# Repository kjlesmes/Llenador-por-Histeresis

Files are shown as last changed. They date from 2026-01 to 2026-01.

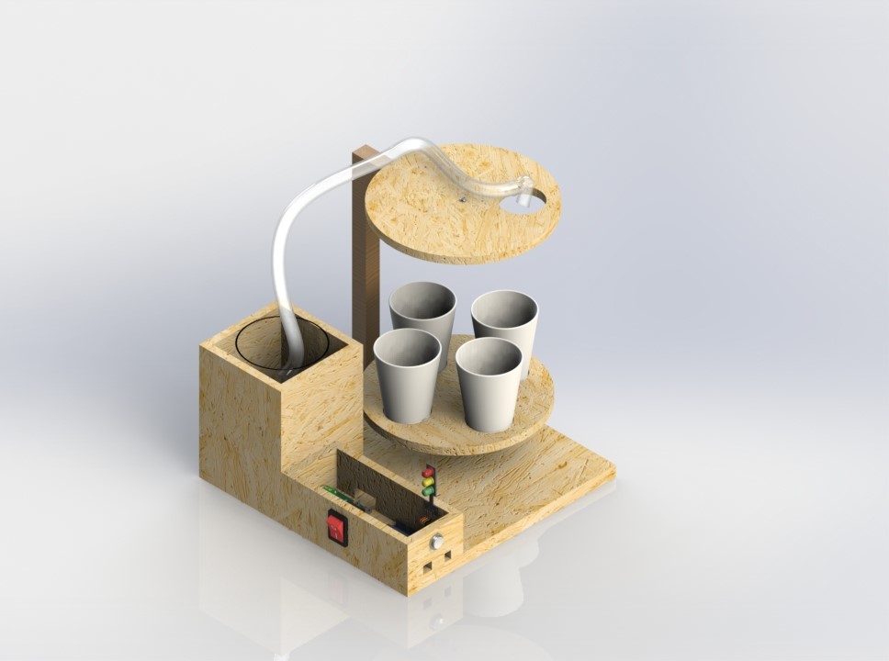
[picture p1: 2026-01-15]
Ensamble.JPG

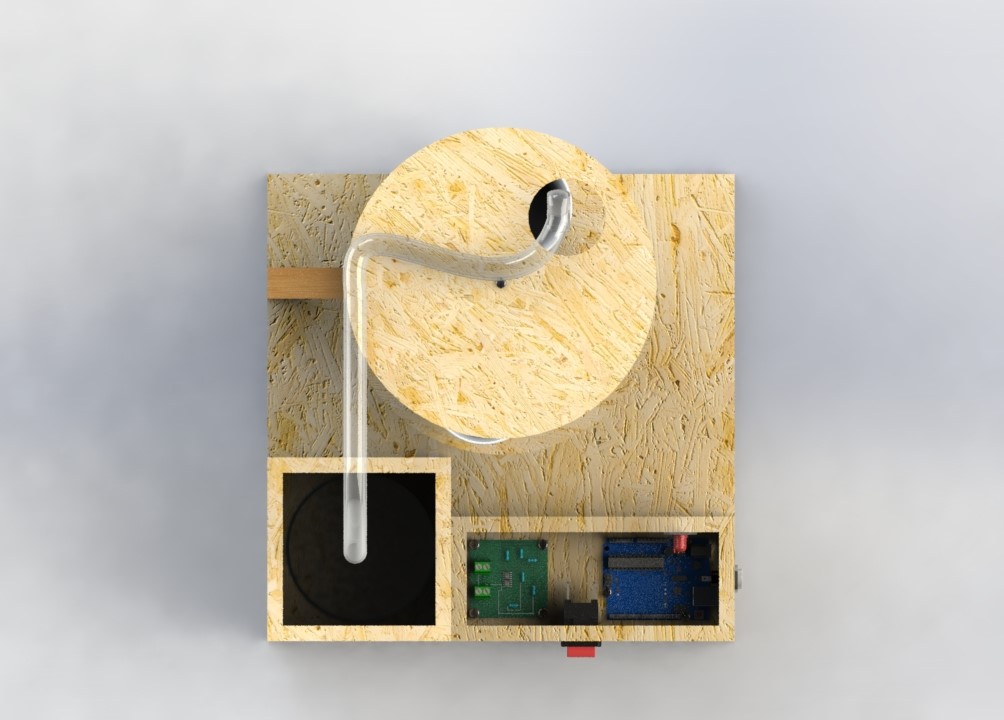
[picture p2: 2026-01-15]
Vista_5.JPG

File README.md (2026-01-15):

# Llenador por Histéresis

## Descripción

Sistema de llenado de líquidos basado en control por histéresis. Este proyecto incluye el diseño mecánico completo de un dispositivo automatizado para el llenado preciso de envases mediante un mecanismo de plato giratorio.

## Estructura del Proyecto

El proyecto está compuesto por los siguientes archivos CAD desarrollados en SolidWorks:

| Archivo | Tipo | Descripción |
|---|---|---|
| `PCB.SLDASM` | Ensamblaje | Ensamblaje principal de la placa de circuito impreso |
| `Base PCB.SLDPRT` | Pieza | Base de soporte para la PCB |
| `Base_Estructura.SLDPRT` | Pieza | Base estructural del sistema |
| `Envase_Agua.SLDPRT` | Pieza | Contenedor de agua/líquido |
| `Plato Giratorio.SLDPRT` | Pieza | Plato rotativo para posicionamiento de envases |
| `Plato_Superior.SLDPRT` | Pieza | Plato superior del mecanismo |
| `Vaso.SLDPRT` | Pieza | Recipiente para llenado |

## Componentes del Sistema

### Mecánicos
- Base estructural principal
- Sistema de plato giratorio para indexación de envases
- Soporte para PCB de control

### Electrónicos
- Placa de circuito impreso (PCB) para control por histéresis
- Sensores de nivel
- Actuadores de llenado

## Principio de Funcionamiento

El sistema utiliza control por histéresis para regular el proceso de llenado:

1. El plato giratorio posiciona el envase en la estación de llenado
2. El sensor de nivel detecta el estado del recipiente
3. El controlador activa/desactiva el flujo según los umbrales de histéresis definidos
4. Una vez alcanzado el nivel objetivo, el plato rota para posicionar el siguiente envase

## Requisitos de Software

- SolidWorks 2020 o superior (para visualización y edición de archivos CAD)
- el acceso a este proyecto completo esta optimizado en mi Drive personal debido a la limitacion de subida de archivos de >25MB de Github. no todos los archivos estan en este repo. https://drive.google.com/drive/folders/1w_ededs4AJgMJ44YJDUHpp9wmpBniWWi

## Licencia

Proyecto de portafolio personal.

## Autor

Ing. Karen lesmes

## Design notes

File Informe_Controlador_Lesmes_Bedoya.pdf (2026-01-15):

### INFORME DE LABORATORIO: CONTROLADOR ON-OFF CON HISTÉRESIS

Karen Juliana Lesmes Calderón, Kevin Santiago Bedoya Merchán Universidad ECCI
Bogotá
karenj.lesmesc@ecci.edu.co, kevins.bedoyam@ecci.edu.co.

Resumen- Este informe presenta el diseño e implementación de un sistema de control ON-OFF con histéresis para el llenado secuencial de frascos, utilizando un comparador LM339N y sensores ultrasónicos HC-SR04. El sistema integra modelado mecánico (SolidWorks), simulaciones electrónicas (Multisim y Proteus) y diseño de PCB (Ultiboard), cumpliendo con normas IPC. Se desarrolló un prototipo simulado en CAD y pruebas preliminares en protoboard que validan la estabilidad y confiabilidad del control, eliminando oscilaciones no deseadas mediante la correcta configuración de histéresis. Aunque no se fabricó la PCB ni la estructura física, las simulaciones y ensambles virtuales demostraron la viabilidad del sistema para
automatizar | procesos | industriales | de | baja
complejidad.

Palabras clave- Comparador LM339N, Control ON-OFF, Diseño PCB, Histéresis, Multisim, SR-HC04.

INTRODUCCIÓN

Los sistemas de control ON-OFF con histéresis son esenciales en procesos industriales que requieren estabilidad y precisión, como el llenado de recipientes, regulación térmica y control de niveles
de | líquidos[1]. | Este | informe | presenta | la
implementación de un sistema de llenado secuencial
de | cuatro | frascos | dispuestos | circularmente,
utilizando un comparador LM339N con histéresis. El
proyecto | integra | componentes | mecánicos,
electrónicos y de software para emular un proceso industrial automatizado, cumpliendo requisitos como sincronización de movimientos (giro de 90° por ciclo), detección de nivel y diseño de PCB conforme a normas IPC[2].

El sistema emplea un disco giratorio impulsado por un motor paso a paso y un disco fijo que soporta los frascos, controlado mediante un circuito ON-OFF con histéresis. Durante el desarrollo se resolvieron problemas como interferencias eléctricas, falsos contactos en el LM339N y errores de ruteo en la PCB, mediante reubicación de componentes, ajuste de resistencias y verificación de continuidad[3]. El diseño mecánico fue modelado en SolidWorks, considerando el espacio para componentes y ruteo [4].

Finalmente, el proyecto valida conceptos teóricos de control automático, como la relación entre la histéresis y el tiempo muerto del sistema [2], y subraya la importancia de integrar simulación (Multisim), diseño de PCB (Ultiboard) y pruebas físicas para lograr soluciones industriales robustas.

MARCO TEORICO

El control ON-OFF con histéresis es una de las estrategias más simples y ampliamente utilizadas en la automatización industrial y doméstica para regular variables como temperatura, nivel de líquidos y presión. Su funcionamiento se basa en la conmutación entre dos estados (encendido y apagado) de un actuador, dependiendo del valor de la variable controlada respecto a un umbral predefinido[1].

Control ON-OFF: El control ON-OFF (también llamado control de dos posiciones o de relé) activa el actuador cuando la variable medida está por debajo de un límite inferior y lo desactiva cuando supera un límite superior. Es útil en sistemas donde se permiten oscilaciones y no se necesita alta precisión[1].

Histéresis en Sistemas ON-OFF: La histéresis es una característica clave en sistemas de control ON-OFF que introduce una zona muerta entre los umbrales de activación y desactivación. Esto evita cambios bruscos y frecuentes ("ciclos rápidos"),
mejorando | la | estabilidad | y | durabilidad | del
sistema[2].

Comparador con Histéresis: El control por histéresis en sistemas electrónicos se implementa
comúnmente | mediante | un | comparador | con
retroalimentación | positiva, | conocido | como
disparador de Schmitt. En este proyecto, se utiliza el
comparador | LM339N, | un | circuito | integrado
ampliamente | empleado | por | su | precisión | y
confiabilidad. | El | voltaje | de | referencia | del
comparador varía en función del estado de la salida,
creando | así | la | banda | de | histéresis.
Matemáticamente, los umbrales de conmutación pueden expresarse como:

V umbral superior = +

R2
R1 + R2

Ecuación 1. Calculo umbral superior

V umbral inferior = −

R2
R1 + R2

Ecuación 2. Calculo umbral inferior

Donde Vsat es la tensión de saturación del comparador y R1 y R2 son las resistencias de la red de realimentación[3].

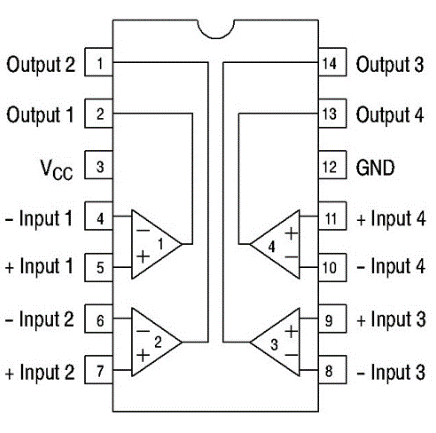
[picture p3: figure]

Figura 1 Datasheet LM339D tomado de: https://acortar.link/ne5cdH

Sensor HC-SR04: El sensor HC-SR04 este compuesto por un emisor y un receptor de ultrasonidos. Estos nos ayudan a medir la distancia a la que se encuentra un objeto justo frente a él, enviando un pulso de ultrasonidos y midiendo el tiempo que transcurre hasta que vuelve dicho pulso[5].

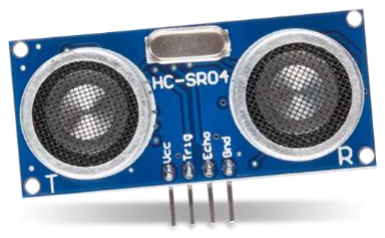
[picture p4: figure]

Figura 2 Sensor ultrasónico HC-SR04 tomado de https://acortar.link/MAJNnS

Arduino Uno: El Arduino Uno es una tarjeta basada en el microcontrolador ATmega328. Tiene 14 pines para entrada/salida digital (6 de estos pueden ser usados como PWM), 6 entradas análogas, oscilador de cristal a 16 MHz, interfaz USB, jack de energía, conector ICSP, y botón de reset.

El Uno se diferencia de sus predecesores en que no usa un integrado conversor UART-USB. En lugar de esto, usa un Atmega16U2 programado como conversor UART-USB[6].

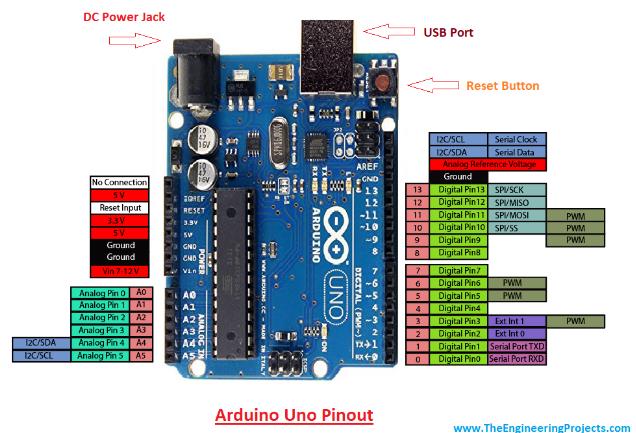
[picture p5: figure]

Figura 3 Datasheet Arduino Uno tomado de: https://acortar.link/ZO41xs

METODOLOGIA

### 1. Diseño del Circuito Electrónico

a. Selección de componentes:
- Comparador LM339N: Configurado con retroalimentación positiva para definir la histéresis (ΔU = 4°C).
- Resistencias de ajuste: Calculadas para establecer umbrales superiores (UH=25°C) e inferior (UL=21°C) mediante: R1=3k y R2=3k

V umbral superior = +

3k
3k + 3k
Relación 0.5

Ecuación 3. Calculo umbral superior

- Resistencias de configuración: Calculadas en función de la ganancia y el voltaje de salida objetivo.

-Resistencia 6.04k x 2: Entre VCC a entrada de cada amplificador.
-Resistencia 2k x 2: Entre GND a entrada de cada amplificador.
- Sensor HC-SR04: Para la detección de distancia, para sensar el nivel de llenado de los vasos.
- Servo | motor | MG-995: | Servomotor | de
piñonería metálica con un torque de hasta 15KG para el giro del plato de llenado.
b. Configuración de histéresis:
- Aplicación de retroalimentación positiva al comparador para evitar chattering.
- Se realiza la simulación en Multisim para validar ΔU y tiempos de conmutación.

### 2. Simulación y esquema eléctrico

a. Modelado del sistema:
- Importación del esquemático electrónico al software.
- Se realiza el diseño del esquema eléctrico en Multisim, analizando y ajustando para obtener el voltaje y la ganancia deseada, para el correcto funcionamiento del circuito.
- | Análisis | transitorio | para | observar | la
respuesta del comparador ante cambios de
| nivel.

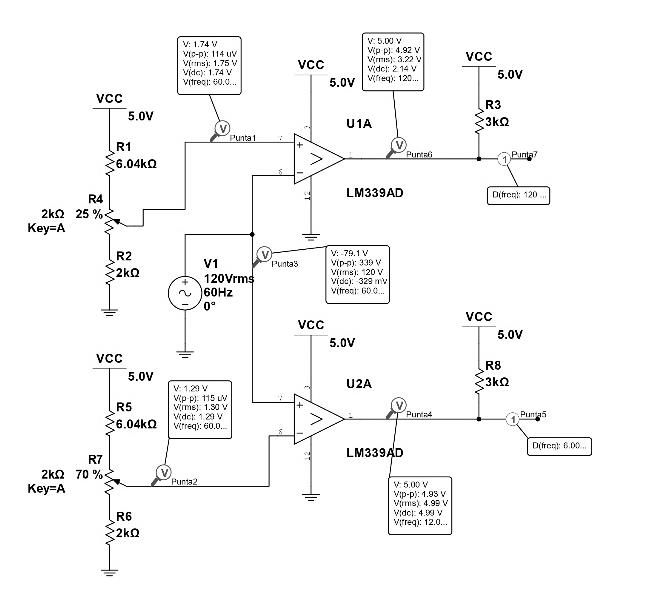
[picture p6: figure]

Esquema 1 Diseño electrónico Multisim

a. Se realiza la simulación en Proteus
utilizando | el | sistema | embebido
seleccionado, para que de esta manera se
pueda | generar | un | prototipo | de
funcionamiento requerido y previsto.
b. Corrección de oscilaciones:
- Ajuste de resistencias en la red de histéresis si se detectan conmutaciones rápidas (>15 ms).

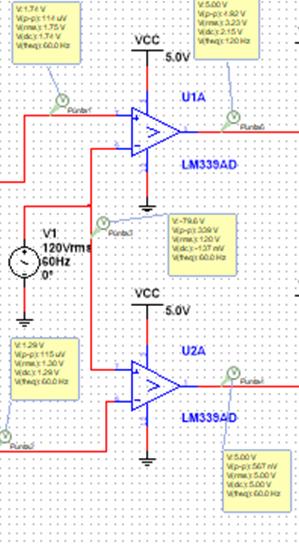
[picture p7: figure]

Esquema 2 Medición de variables para revisión de oscilaciones

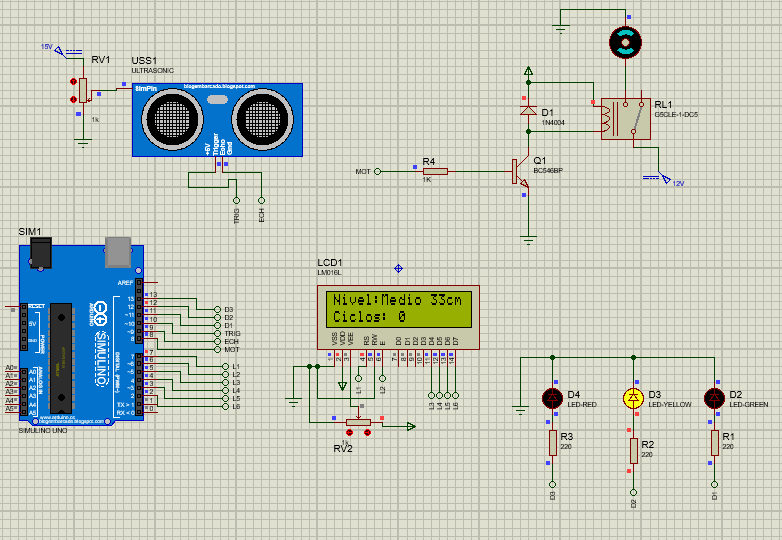
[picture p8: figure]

Esquema 3 Simulación en Proteus funcionando

c. Validación de parámetros:
- Verificación de la señal cuadrada en el
osciloscopio | virtual | (amplitud: | 0-5 | V,
frecuencia: 1-10 Hz).

### 3. Implementación en Laboratorio

a. Montaje físico en protoboard:
- | Conexión | independiente | de | cables | de
alimentación y señal para evitar ruido.

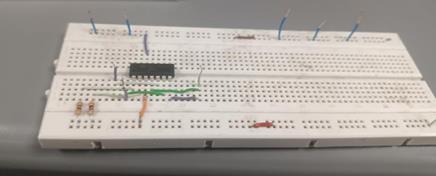
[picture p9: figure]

Figura 4 Montaje en Protoboard

- Uso de multímetro para verificar continuidad en conexiones críticas (ej. transistor-salida).

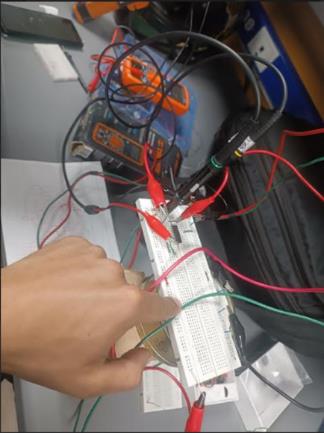
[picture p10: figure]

Figura 5 Configuración de cada conexión independiente

b. Pruebas iniciales:
- Medición de la señal del comparador con osciloscopio (KEYSIGHT DSOX1102G):

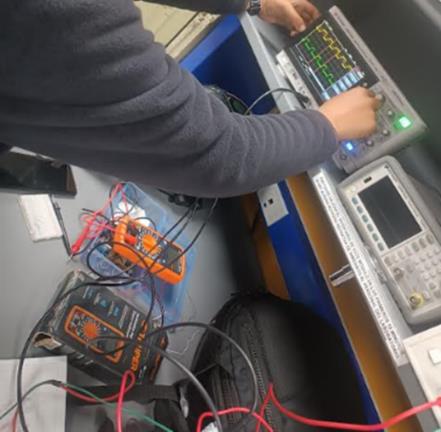
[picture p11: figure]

Figura 6 Verificación de señal y parámetros en el Osciloscopio

- Amplitud de ruido aceptable: <0.5 Vpp.

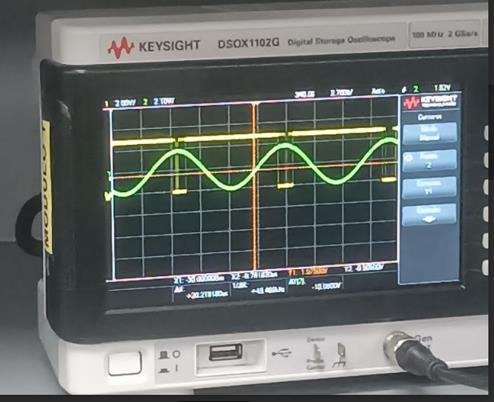
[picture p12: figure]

Ilustración 1 Verificación de las señales en el osciloscopio

### 4. Diseño de PCB en Ultiboard

a. Ruteo de pistas:
- Separación mínima de 0.3 mm entre trazas críticas (ej. salida del LM339N a la base del transistor).

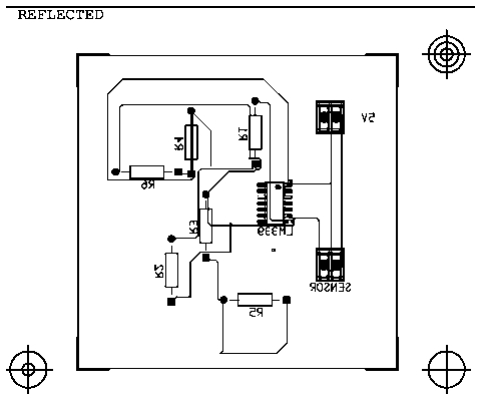
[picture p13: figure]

Esquema 4 Esquema de impresión para PCB

- Ancho de pistas: 0.5 mm (señales), 2 mm (alimentación) para reducir resistencia.

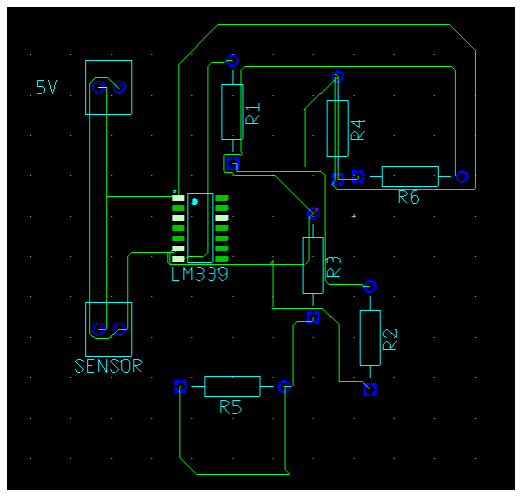
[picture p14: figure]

Esquema 5 Esquema circuito PCB

b. Prevención de interferencias:
- Conexión independiente de cada tierra y alimentación para cada punta del amplificador. Agrupación de tierras analógicas y digitales.

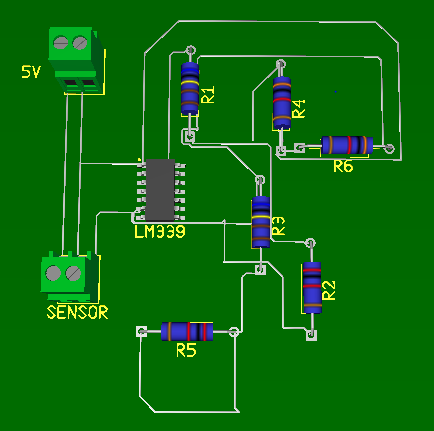
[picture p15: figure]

Esquema 6 PCB en diseño 3D

### 5. Diseño y Simulación de la estructura

a. Diseño de la base y elementos estructurales en SolidWorks:
- Se desarrolla inicialmente la base donde se construirá todo el modelo del proyecto. Se utiliza una visualización de madera OSB que es estético y cumple con los requisitos para la construcción del prototipo.

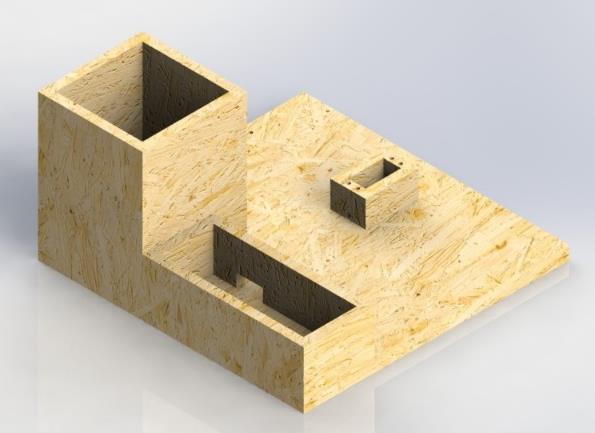
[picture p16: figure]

Figura 7 Base del prototipo

- Se construye según las medidas mínimas requeridas para el proyecto, un plato giratorio de 20cm

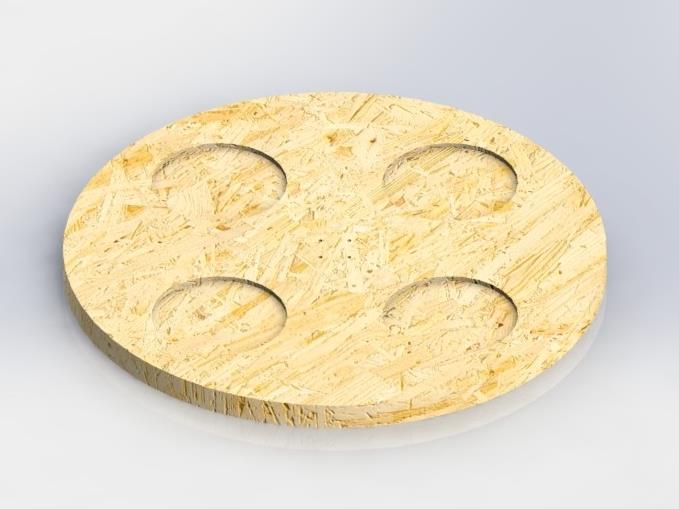
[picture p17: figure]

Figura 8 Plato giratorio

- Se construye el soporte del plato superior con el requerimiento de 20cm del plato al vaso, altura total de 28cm. Se realiza el diseño del plato superior con un diámetro de 20cm y un agujero para la caída del líquido. Además, se diseña el vaso para la simulación.

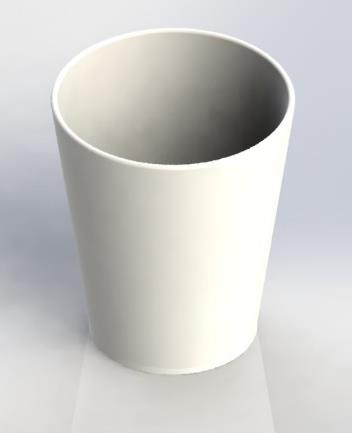
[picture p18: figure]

Figura 9 Diseño Vaso de icopor

- Se hace el diseño el deposito de agua y su enrutado de manguera para el llenado con agua.

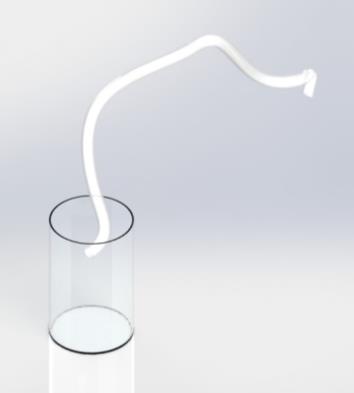
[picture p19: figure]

Figura 10 Diseño depósito del agua y enrutado de manguera b. Elementos electrónicos y actuadores para el diseño (no diseñados)

Elementos tomados de bibliotecas de internet para el diseño del prototipo.

- Arduino Uno para sistema embebido[7]

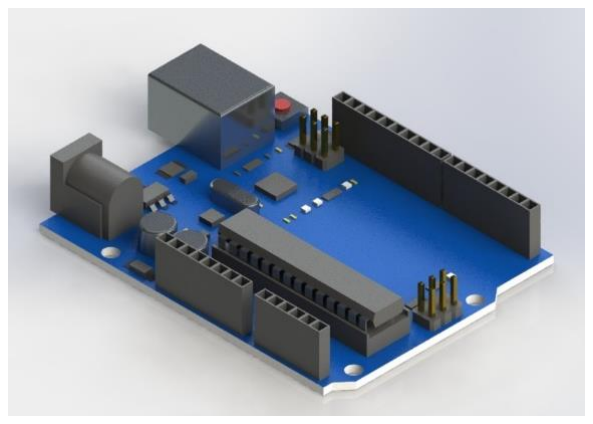
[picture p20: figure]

Figura 11 CAD Arduino Uno

- Servo motor MG995 para la rotación del plato giratorio[8]

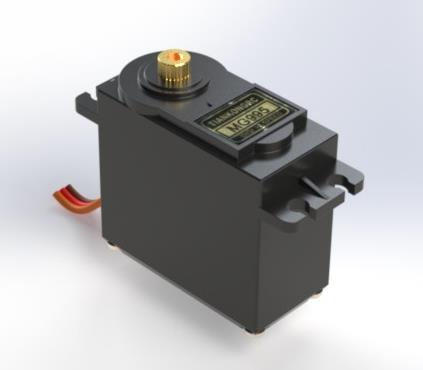
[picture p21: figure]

Figura 12 Servomotor MG995 de torque 15kg

- Botón ON-OFF[9]
- Pulsador de Reset[10]
- Led semáforo para la indicación de llenado[11].
c. Diseño del sistema de sensado y potencia
- Diseño PCB: El diseño fue realizado totalmente manual en SolidWorks para la incorporación en el diseño y simulación lo más realista posible[4].

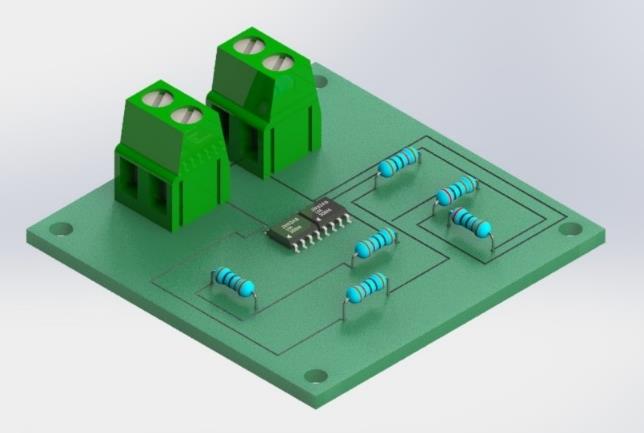
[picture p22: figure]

Figura 13 PCB diseñada en SolidWorks

- Sensor HC-SR04: Sensor tomado como elemento electrónico de internet, para ser incluido en el diseño[12].

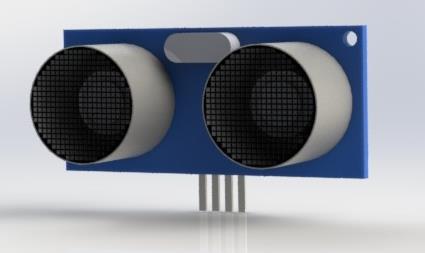
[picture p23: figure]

Figura 14 Diseño Sensor HC-SR04

b. Ensamble del prototipo
- Se realizó el ensamble del prototipo, haciendo croquis de ensamble y relaciones de posición para ubicar el diseño como se preveía para construcción.

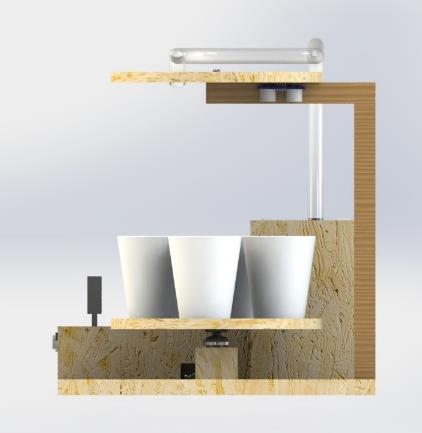
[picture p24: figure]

Figura 15 Ensamble elementos mecánicos y estructurales

- Ubicación de elementos electrónicos para el tablero de control:

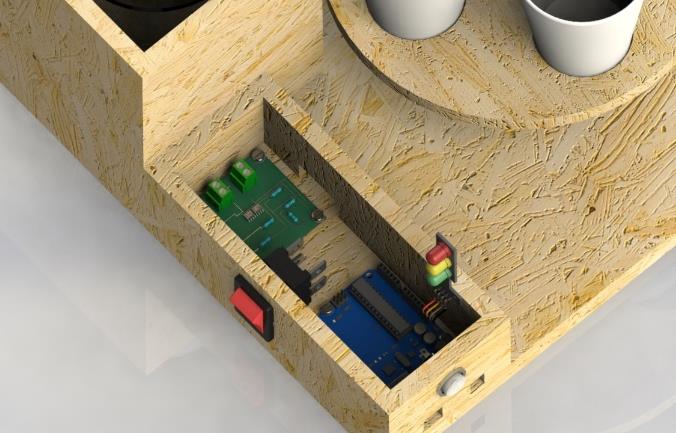
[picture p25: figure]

Figura 16 Tablero de control con botones y leds de llenado

- Finalmente se tiene el prototipo con todas sus partes ensamblado, para más detalles se pueden comprobar en la vista explosiva e implosiva en los videos adjuntos.

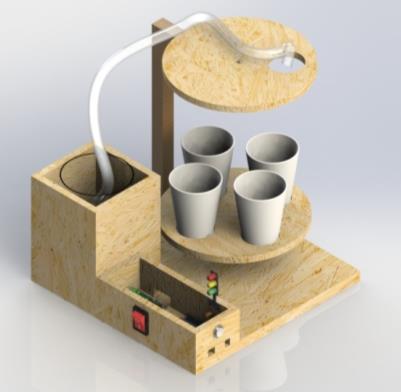
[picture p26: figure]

Figura 17 Isométrico estructura prototipo

RESULTADOS

Resultados de Simulación y Pruebas en Laboratorio

### 1. Simulación en Multisim:

El circuito del controlador ON-OFF con histéresis fue modelado y simulado exitosamente. Se verificó que el comparador LM339N, configurado
con | retroalimentación | positiva, | respondía
correctamente a los cambios de nivel simulados por el sensor. La señal de salida mostró transiciones claras entre los estados ON y OFF al alcanzar los
umbrales | definidos, | evitando | oscilaciones
indeseadas gracias a la histéresis implementada[4].

### 2. Diseño de PCB:

Se realizó el diseño del circuito 3D(PCB) en Ultiboard, cumpliendo con las normas IPC para el ancho y separación de pistas, puntos de prueba y disposición de componentes. El layout fue verificado mediante las herramientas de diseño, asegurando la
factibilidad | de | fabricación | y | el | correcto
funcionamiento | del | sistema | en | condiciones
ideales[13].

### 3. Pruebas en protoboard:

Aunque no se construyó la PCB física, se realizaron pruebas preliminares en protoboard para validar el funcionamiento básico del controlador y la lógica de control. Se observó que el sistema respondía adecuadamente a la simulación de señales de nivel, conmutando el estado del motor y los indicadores según lo esperado[14].

### 4. Prototipo simulado en CAD

Aunque no se realizó la estructura física, se realizó un prototipo simulado en CAD, para demostrar la previsualización del proyecto y el funcionamiento mecánico.

### 5. Limitaciones y Observaciones

a. No se construyó la PCB:

Por motivos logísticos y de recursos, no fue posible fabricar la tarjeta PCB ni montar la estructura giratoria de los discos y frascos. Por tanto, todos los resultados prácticos corresponden a simulaciones y
pruebas | en | protoboard, | sin | validación | en
condiciones reales de operación.
b. Estabilidad y robustez del sistema:
Las | simulaciones | demostraron | que | la
implementación de histéresis en el comparador elimina el problema del “chattering” y mejora la estabilidad del sistema, permitiendo un control confiable del proceso de llenado automático.

CONCLUSIONES

El desarrollo del sistema de control ON-OFF con histéresis para el llenado automático de frascos permitió validar, a través de simulaciones y pruebas en protoboard, el funcionamiento estable y confiable de la lógica de control propuesta, cumpliendo con los objetivos planteados para la automatización de un proceso circular industrial sencillo.

La implementación de la histéresis en el comparador LM339N demostró ser fundamental
para | evitar | oscilaciones | indeseadas | y
conmutaciones frecuentes en la salida, mejorando la estabilidad del sistema y protegiendo los elementos de actuación, tal como se evidencia en los resultados de laboratorio.

Las simulaciones en Multisim confirmaron el correcto comportamiento del controlador: la señal de salida cambiaba de estado únicamente al alcanzar los umbrales definidos. Además, la simulación en Proteus, se comprueba el funcionamiento del sistema enviado a la realidad.

La imposibilidad de construir la PCB y la estructura física limitó la validación del sistema en condiciones reales; sin embargo, el diseño electrónico y el layout de la PCB cumplen con las especificaciones técnicas y normativas requeridas, estando listos para su fabricación y montaje.

El trabajo realizado permitió comprender la importancia de una adecuada configuración de la histéresis en sistemas ON-OFF, así como la relevancia de las etapas de simulación y pruebas preliminares antes de la implementación física, para identificar y corregir posibles errores de diseño y asegurar la funcionalidad del sistema.

En conclusión, el proyecto sienta una base sólida para la futura implementación física del sistema, demostrando la viabilidad y eficiencia del control ON-OFF con histéresis en aplicaciones de baja complejidad, y resalta la importancia de la simulación y el prototipado en el desarrollo de soluciones mecatrónicas.

| | REFERENCIAS
[1] Ing. Lucía Hernandez, “Qué es el control de histéresis en sistemas ON/OFF .” Accessed: Apr. 23, 2025. [Online]. Available: https://sonilec.mx/que-es-el-control-de-histeresis-en-sistemas-on-off/?expand_article=1
[2] Ing. Mec. Marcos A. Golato, “ACCIONES DE CONTROL,” May 2016. Accessed: Apr. 23, 2025. [Online]. Available: https://catedras.facet.unt.edu.ar/sistemasdec
| ontrol/wp-

content/uploads/sites/101/2016/04/5_Accion es-de-control_2016.pdf

[3] “7.5: Comparadores - LibreTexts Español.” Accessed: Apr. 23, 2025. [Online]. Available: https://espanol.libretexts.org/Ingenieria/Amplificadores_Operacionales_y_Circuitos_Integrados_Lineales_-
_Teoria_y_Aplicacion_(Fiore)/07%3A_Circuit os_no_lineales/7.05%3A_Comparadores
[4] Karen Lesmes, “Argumentos propios,” 2025.
[5] Leantec, “Datasheet HC-SR04.” [Online]. Available: www.leantec.es
[6] “ARDUINO UNO R3 CON CABLE USB.” Accessed: Apr. 27, 2025. [Online]. Available: https://www.mactronica.com.co/arduino-uno-r3-con-cable-usb
[7] “Arduino Uno | 3D CAD Model Library |
GrabCAD.” Accessed: Apr. 27, 2025. [Online]. Available:
https://grabcad.com/library/arduino-uno-36
[8] “MG995 Servo | 3D CAD Model Library |
GrabCAD.” Accessed: Apr. 27, 2025. [Online]. Available:
https://grabcad.com/library/mg995-servo-3
[9] “ON OFF TUŞU | 3D CAD Model Library |
GrabCAD.” Accessed: Apr. 27, 2025. [Online]. Available:
https://grabcad.com/library/on-off-tusu-1
[10] “small push button | 3D CAD Model Library |
GrabCAD.” Accessed: Apr. 27, 2025. [Online]. Available:
https://grabcad.com/library/small-push-button-1
[11] “Traffic lights LED module | 3D CAD Model
Library | GrabCAD.” Accessed: Apr. 27,
2025. [Online]. Available: https://grabcad.com/library/traffic-lights-led-module-1
[12] “HC-SR04 | 3D CAD Model Library |
GrabCAD.” Accessed: Apr. 27, 2025. [Online]. Available:
https://grabcad.com/library/hc-sr04-16/details?folder_id=14112831
[13] Ing. Ana Sabrina Niño, “IPC 2220 PCB”.
[14] Kevin Bedoya, “Argumentos Propios,” 2025.

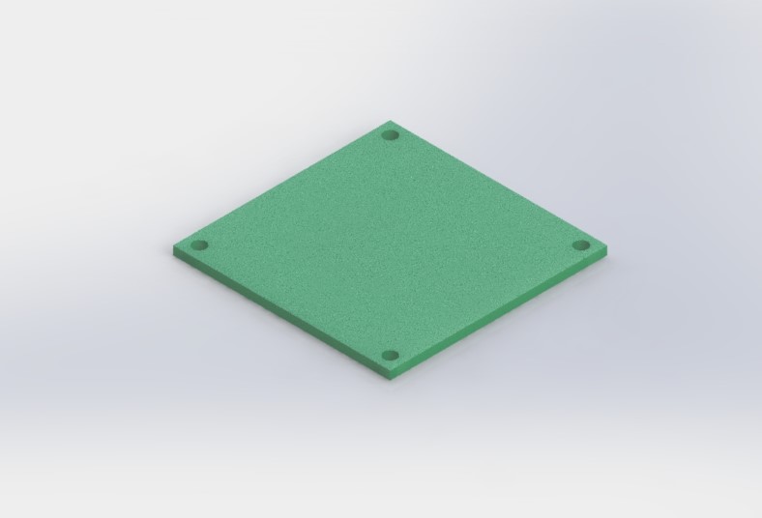
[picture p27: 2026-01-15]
Base_PCB.JPG

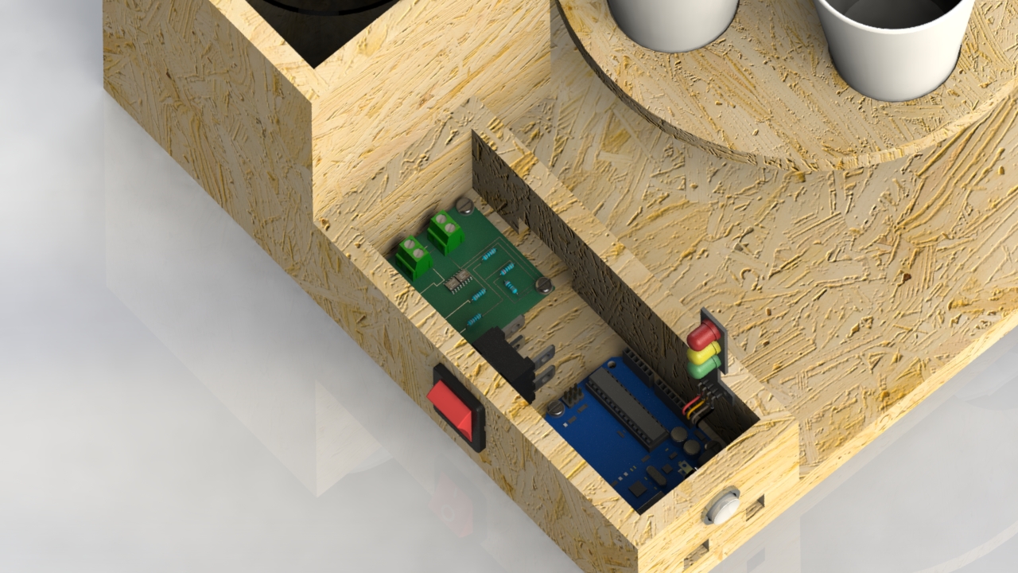
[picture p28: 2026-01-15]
Vista_6.JPG

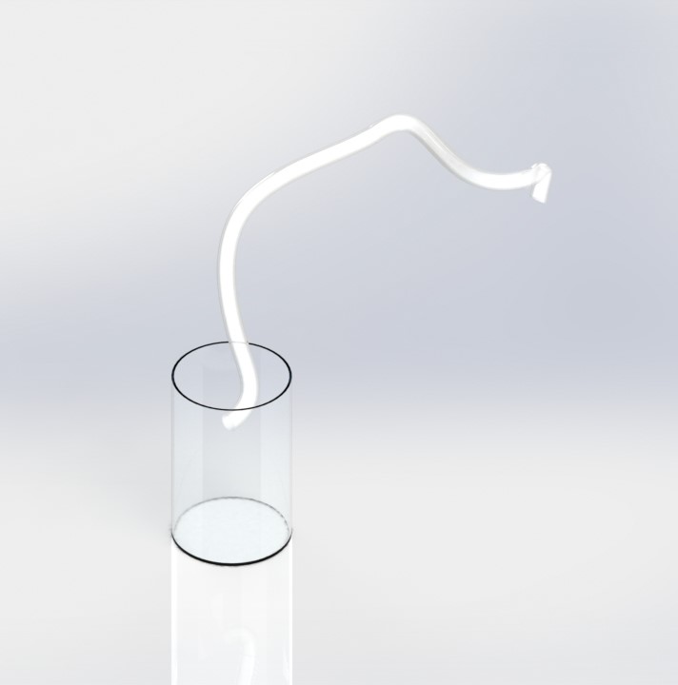
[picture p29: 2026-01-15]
Envase_Agua.JPG

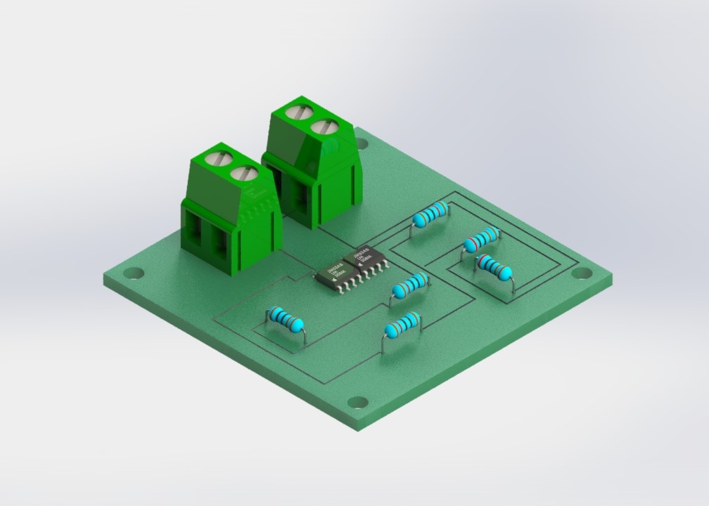
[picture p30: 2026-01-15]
PCB.JPG

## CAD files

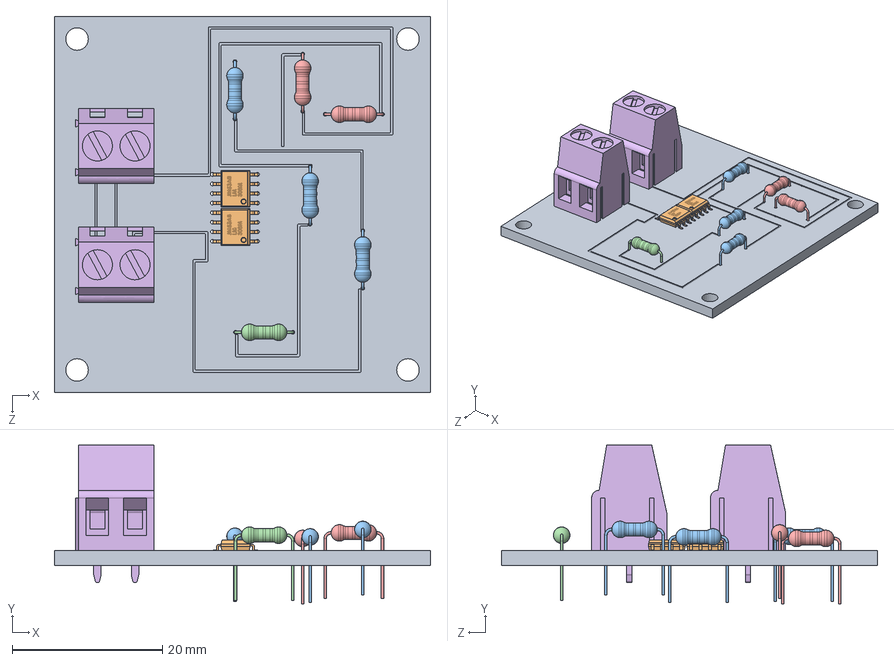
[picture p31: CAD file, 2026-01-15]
PCB.SLDASM
50.0 x 21.1 x 50.0 mm
Base PCB
LM308M OPERATIONAL AMPLIFIER x 2
10KR x 3
1KR
2KR x 2
KRE_2 x 2

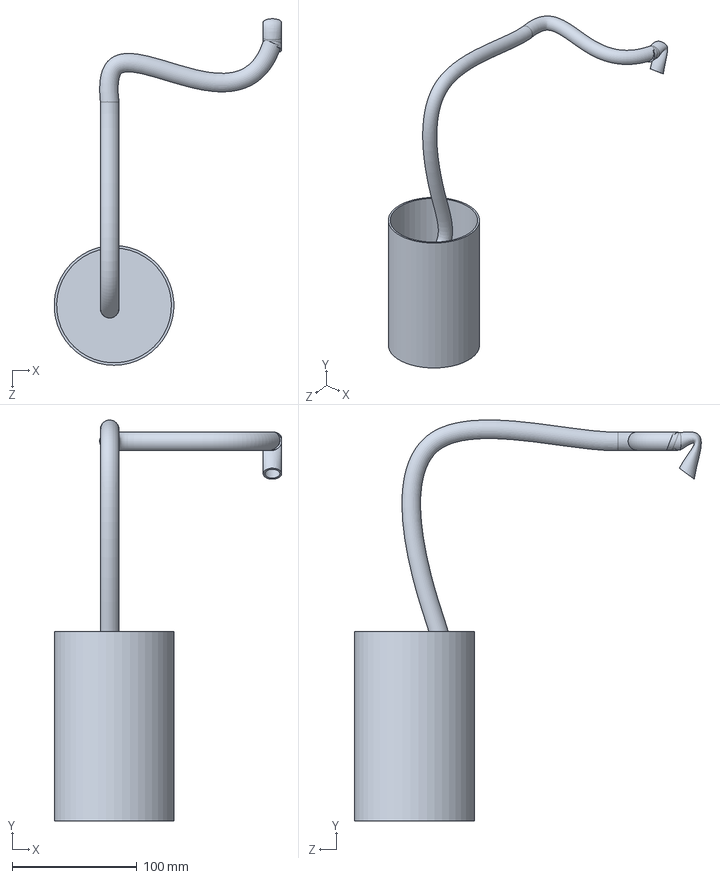
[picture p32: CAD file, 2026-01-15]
Envase_Agua.SLDPRT
182.7 x 322.0 x 278.4 mm

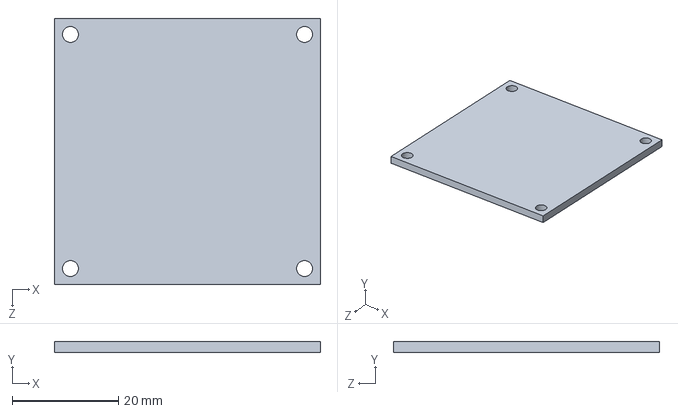
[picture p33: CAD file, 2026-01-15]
Base PCB.SLDPRT
50.0 x 2.00 x 50.0 mm

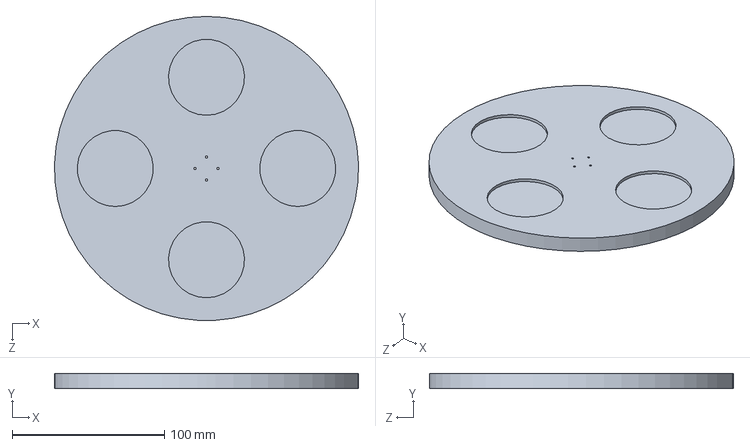
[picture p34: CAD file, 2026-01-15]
Plato Giratorio.SLDPRT
199.9 x 10.0 x 200.0 mm

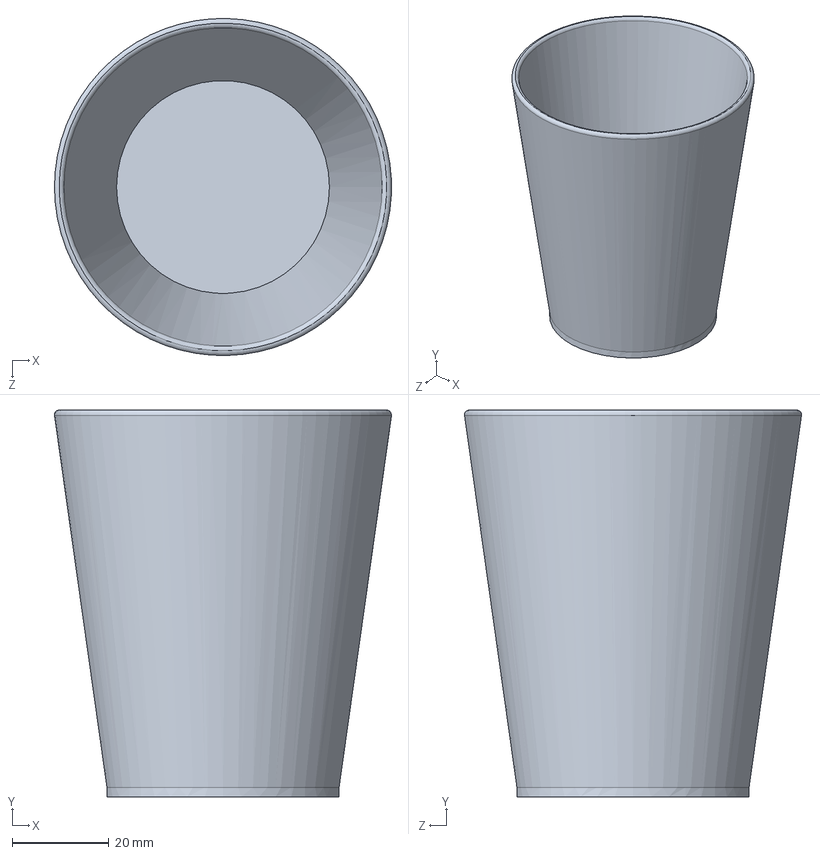
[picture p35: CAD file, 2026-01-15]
Vaso.SLDPRT
69.7 x 80.0 x 69.7 mm

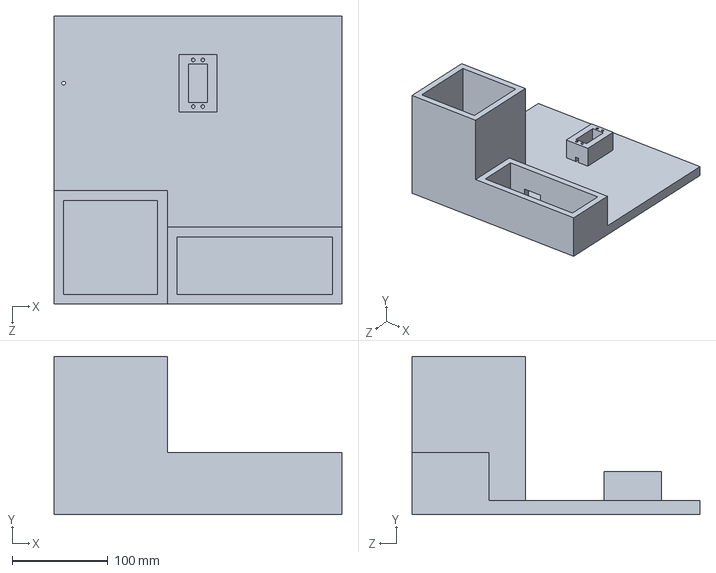
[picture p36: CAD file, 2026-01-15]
Base_Estructura.SLDPRT
300.0 x 165.0 x 300.0 mm

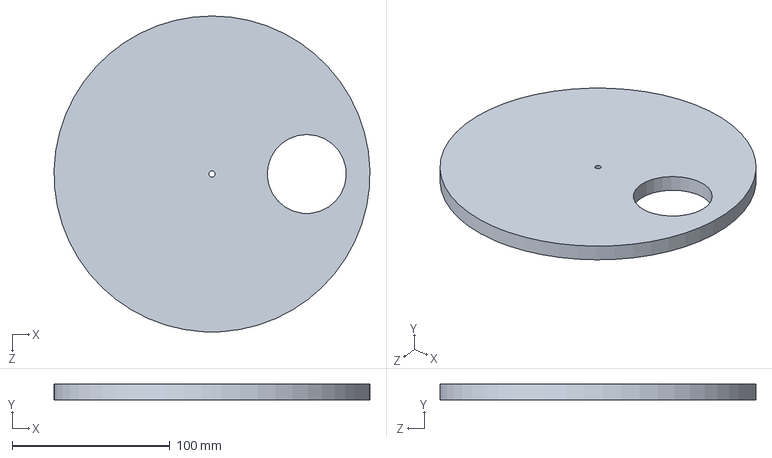
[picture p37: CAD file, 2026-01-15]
Plato_Superior.SLDPRT
199.9 x 10.0 x 200.0 mm
